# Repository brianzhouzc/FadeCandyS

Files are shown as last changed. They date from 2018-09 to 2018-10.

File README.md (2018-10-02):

# FadeCandy S

FadeCandyS, which stands for FadeCandy Slim, is a modified version of the original [FadeCandy](https://github.com/scanlime/fadecandy) by scanlime. It's designed to be the same width as an [Adafruit NeoPixel Stick](https://www.adafruit.com/product/1426) and can be directly soldered onto the back of the NeoPixel Stick. It only uses one pin instead of the 8 pins on the original FadeCandy, thus is only capable of controlling 64LEDs maximum.

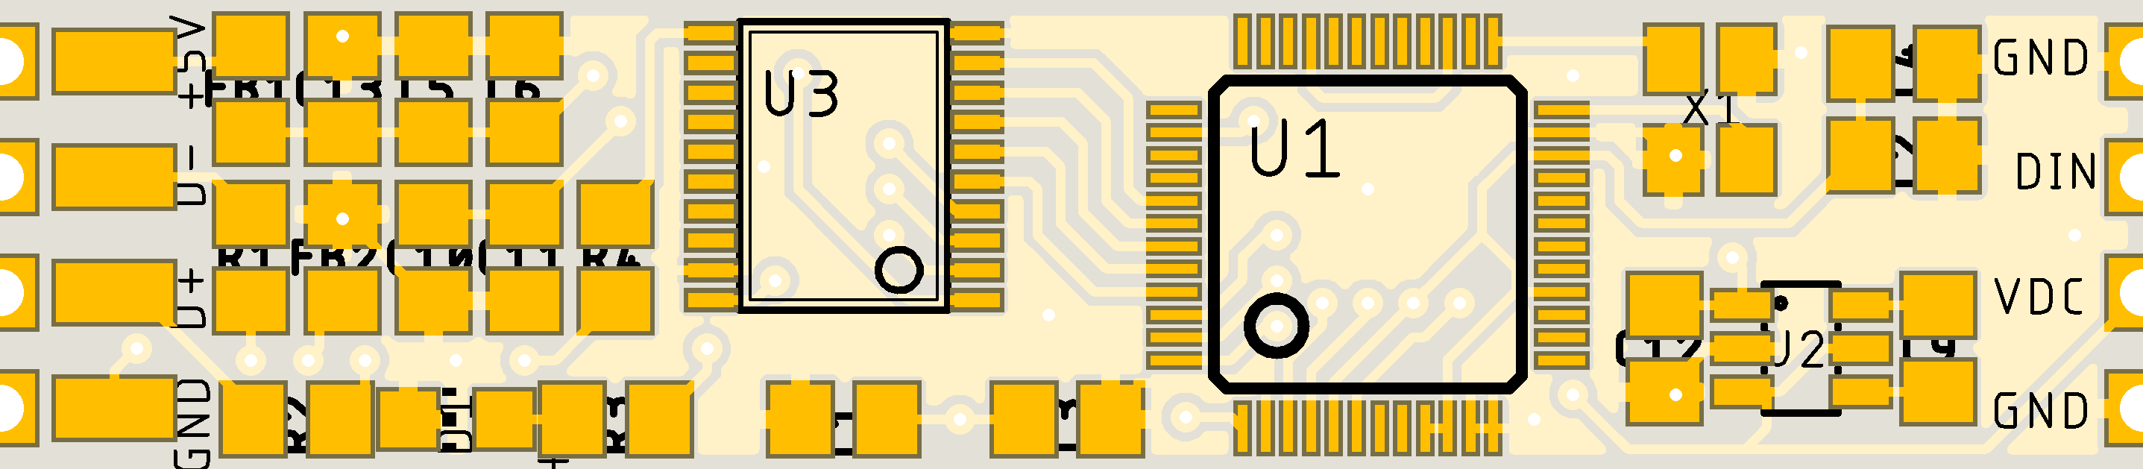
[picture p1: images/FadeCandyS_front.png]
FRONT


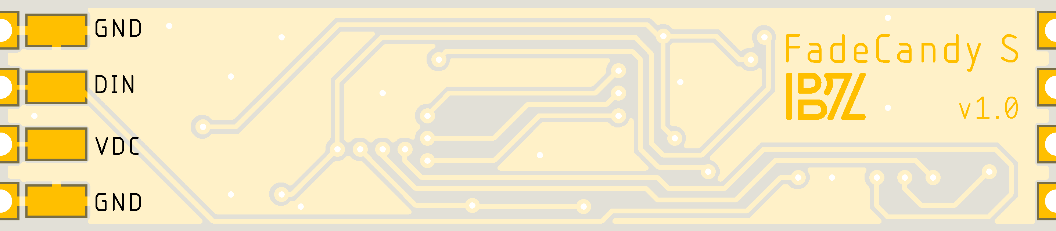
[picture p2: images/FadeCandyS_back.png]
BACK


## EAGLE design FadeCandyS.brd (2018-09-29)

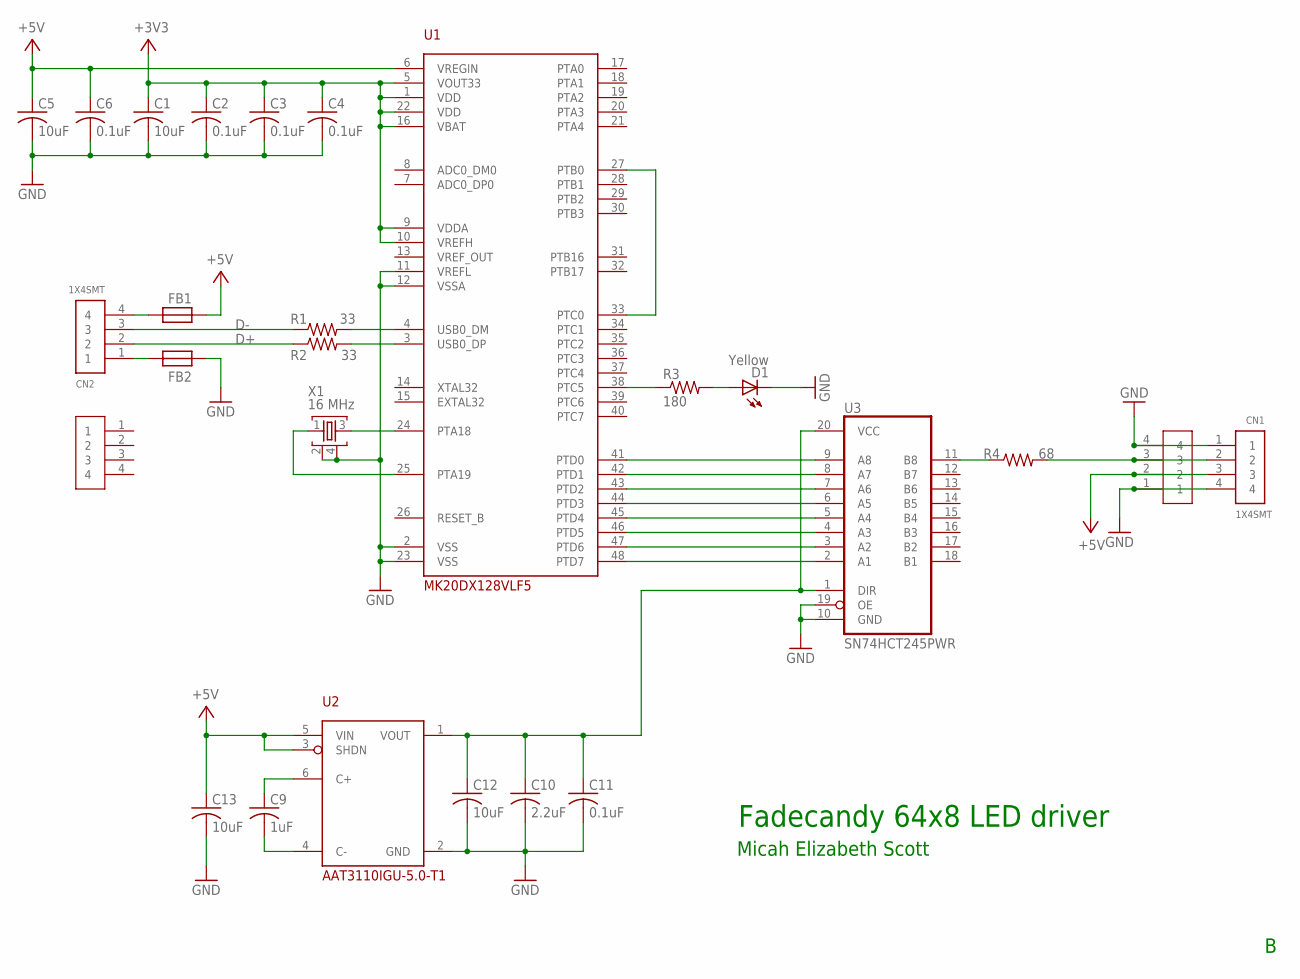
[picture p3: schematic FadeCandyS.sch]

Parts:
1X4_HALFVIA: 1X4_HALFVIA
C1, C5, C12, C13: 10uF; 0805
C2, C3, C4, C6, C11: 0.1uF; 0805
C9: 1uF; 0805
C10: 2.2uF; 0805
CN1, CN2: 1X4SMT; 1X4-SMT
D1: Yellow; CHIP-LED0805
FB1, FB2: FB0805/NO-OUTLINE; 0805
R1, R2: 33; 0805
R3: 180; 0805
R4: 68; 0805
U1: MK20DX128VLF5; LQFP48
U2: AAT3110IGU-5.0-T1; SOT23-6L
U3: SN74HCT245PWR; TSSOP20
U$1: 1X4_HALFVIA
X1: 16 MHz; TSX-3225

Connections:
+3V3: C1.1, C2.1, C3.1, C4.1, U1.1 (VDD), U1.5 (VOUT33), U1.9 (VDDA), U1.10 (VREFH), U1.16 (VBAT), U1.22 (VDD)
+5V: 1X4_HALFVIA.2, C5.1, C6.1, C13.1, CN1.3, FB1.2, U1.6 (VREGIN), U2.3 (SHDN), U2.5 (VIN)
D+: CN2.2, R2.1
D-: CN2.3, R1.1
GND: 1X4_HALFVIA.1, 1X4_HALFVIA.4, C1.2, C2.2, C3.2, C4.2, C5.2, C6.2, C10.2, C11.2, C12.2, C13.2, CN1.1, CN1.4, D1.C, FB2.2, U1.2 (VSS), U1.11 (VREFL), U1.12 (VSSA), U1.23 (VSS), U2.2 (GND), U3.10 (GND), U3.19 (OE), X1.2, X1.4
unnamed: R3.1, U1.38 (PTC5)
unnamed: U1.24 (PTA18), X1.3
unnamed: D1.A, R3.2
unnamed: U1.25 (PTA19), X1.1
unnamed: CN2.4, FB1.1
unnamed: U1.27 (PTB0), U1.33 (PTC0)
unnamed: CN2.1, FB2.1
unnamed: U1.41 (PTD0), U3.9 (A8)
unnamed: 1X4_HALFVIA.3, CN1.2, R4.2
unnamed: R1.2, U1.4 (USB0_DM)
unnamed: R2.2, U1.3 (USB0_DP)
unnamed: U1.42 (PTD1), U3.8 (A7)
unnamed: U1.43 (PTD2), U3.7 (A6)
unnamed: U1.44 (PTD3), U3.6 (A5)
unnamed: U1.45 (PTD4), U3.5 (A4)
unnamed: U1.46 (PTD5), U3.4 (A3)
unnamed: U1.47 (PTD6), U3.3 (A2)
unnamed: U1.48 (PTD7), U3.2 (A1)
unnamed: R4.1, U3.11 (B8)
unnamed: C9.1, U2.6 (C+)
unnamed: C9.2, U2.4 (C-)
unnamed: C10.1, C11.1, C12.1, U2.1 (VOUT), U3.1 (DIR), U3.20 (VCC)

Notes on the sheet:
Fadecandy 64x8 LED driver
Micah Elizabeth Scott

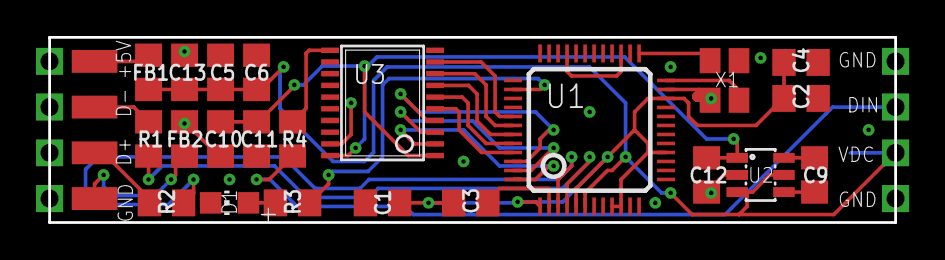
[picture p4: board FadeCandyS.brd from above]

Board: 2 copper layers, 47.0 x 10.3 mm, 26 parts (1 on the bottom side), 27 nets.
